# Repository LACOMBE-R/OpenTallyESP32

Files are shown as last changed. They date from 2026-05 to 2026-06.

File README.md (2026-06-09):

# OpenTallyESP32

A wireless tally light system built around the **Seeed XIAO ESP32-C3**. Each unit connects to a WebSocket tally server over Wi-Fi and lights up its two NeoPixel LEDs to show the live camera state (Program / Preview / Idle). Battery level is reported to the server automatically.

This project was created for the [orKs](https://lce.gg/) association for the **LCE** ([lce.gg](https://lce.gg/)) event, to manage camera tally signaling during live productions.

---

## Hardware

| Component | Details |
|---|---|
| MCU | Seeed Studio XIAO ESP32-C3 |
| LEDs | 3× NeoPixel (WS2812B), pin **D8** — 2 rear + 1 front-facing |
| Button | Tactile switch, pin **D1** (GPIO 3) |
| Battery sensing | Enable pin **D0**, ADC pin **D2** — voltage divider, 3.0 V–4.2 V range |

The KiCad schematic and PCB layout are in [`ECAD/OpenTallyESP32/`](ECAD/OpenTallyESP32/).

---

## Firmware

### Prerequisites

- [PlatformIO](https://platformio.org/) (VS Code extension or CLI)

### Credentials

Sensitive values (WiFi credentials, WebSocket server) are kept out of version control in a local file:

```
Firmware/OpenTallyESP32/include/credentials.h
```

This file is listed in `.gitignore` and will never be committed. Before building, copy the example file and fill in your values:

```bash
cp include/credentials.h.example include/credentials.h
```

```cpp
#define DEFAULT_WIFI_SSID  "your_ssid"
#define DEFAULT_WIFI_PASS  "your_password"
#define DEFAULT_WS_HOST    "your.websocket.server"
#define DEFAULT_WS_PORT    80
```

These defines are used as fallback defaults when no configuration has been saved to flash yet. Once configured via the dashboard, the flash values take over and these defaults are no longer used.

### Dependencies (resolved automatically by PlatformIO)

- `adafruit/Adafruit NeoPixel`
- `links2004/WebSockets`
- `bblanchon/ArduinoJson`

---

## Configuration

### NVS flash storage

Configuration is persisted in the ESP32's **NVS (Non-Volatile Storage)** — a key-value store built into the flash that survives resets and power cuts. The Arduino `Preferences` library is used to read and write it under the namespace `opentally`.

Values are written only when the user submits the config form; they are read once at every boot before anything else runs. If a key has never been written, the firmware falls back to the compiled-in default shown below.

| Key | Type | Default | Description |
|-----|---|---|---|
| `camera_id` | string | `cam01` | Camera identifier sent in every WebSocket message |
| `ws_host` | string | `your.websocket.server` | WebSocket server hostname |
| `ws_port` | uint16 | `80` | WebSocket server port |
| `wifi_ssid` | string | — | Wi-Fi network name |
| `wifi_pass` | string | — | Wi-Fi password |

### Entering configuration mode

Hold the button for **5 seconds** at power-on (or after waking from deep sleep). The LEDs will turn **solid purple** to confirm the long-press was detected.

The device starts a Wi-Fi access point:

- **SSID:** `OpenTally-Config`
- **Password:** `opentally`

Connect to it and open **http://192.168.4.1** in a browser. Fill in the form and click *Configurer*. The device saves the settings to NVS, confirms with a countdown banner, then restarts into normal mode.

### Operating modes — flowchart

```
                        ┌─────────────────┐
                        │   Power on /    │
                        │  Wake from deep │
                        │      sleep      │
                        └────────┬────────┘
                                 │
                        Load NVS config
                                 │
                    ┌────────────▼────────────┐
                    │  Button held on boot?   │
                    └────┬──────────────┬─────┘
                  Yes ≥5s│              │No
                         │              │
           ┌─────────────▼──┐    ┌──────▼───────────────┐
           │   AP / Config  │    │     Normal mode      │
           │     mode       │    │  Connect to Wi-Fi    │
           │ SSID: OpenTally│    └─────┬────────────────┘
           │ IP: 192.168.4.1│          │
           │ LEDs: purple   │    ┌─────▼─────────────────────┐
           │   blink        │    │  Wi-Fi connected in 30s?  │
           └─────────┬──────┘    └──┬─────────────────────┬──┘
                     │           No │                     │ Yes
              Serve config    ┌─────▼──────┐    ┌─────────▼──────────┐
                  form        │ Deep sleep │    │  Connect WebSocket │
                     │        └────────────┘    └─────────┬──────────┘
              User submits                                │
                     │                       ┌────────────▼───────────┐
              Save to NVS                    │      Main loop         │
                     │                       │  ┌──────────────────┐  │
                  Restart                    │  │ WS msg received  │  │
                                             │  │  → update LEDs   │  │
                                             │  │    RED / GREEN / │  │
                                             │  │      OFF         │  │
                                             │  └──────────────────┘  │
                                             │  ┌──────────────────┐  │
                                             │  │ Every 30s        │  │
                                             │  │ → send battery % │  │
                                             │  └──────────────────┘  │
                                             │  ┌──────────────────┐  │
                                             │  │ Button press     │  │
                                             │  │  → deep sleep    │  │
                                             │  └──────────────────┘  │
                                             └────────────────────────┘
```

---

## Operation

### Boot sequence

1. Device loads saved configuration from NVS.
2. If button is held ≥ 5 s → **AP / config mode** (see above).
3. Otherwise → **normal mode**: connects to the configured Wi-Fi.

### LED states

The device has two **rear LEDs** (visible to the operator) and one **front LED** (visible to the talent, facing the subject).

**Tally states**

| State | Rear LEDs (0 & 1) | Front LED (2) |
|---|---|---|
| Program (on air) | Red | Red |
| Preview | Green | Off |
| Program + Preview | Red (program takes priority) | Red |
| Idle | Off | Off |

**Status patterns**

Slow-blink patterns affect rear LEDs only (front LED stays off). Quick-flash patterns fill all 3 LEDs.

| Color | Pattern | Front LED | Meaning |
|---|---|---|---|
| Blue | Slow blink | Off | Connecting to Wi-Fi |
| Green | 5 quick flashes | On | Wi-Fi connected |
| Red | Slow blink | Off | WebSocket disconnected |
| Purple | Slow blink | Off | AP config mode active |
| Red | 3 quick flashes | On | Entering deep sleep |

### Power saving

- After Wi-Fi connects the CPU is throttled to **80 MHz** and Wi-Fi modem-sleep is enabled.
- Press the button at any time — including during Wi-Fi connection — to immediately enter **deep sleep**. The device will wake again on the next button press.
- If Wi-Fi does not connect within **30 seconds**, the device goes to deep sleep automatically.

### Battery reporting

On WebSocket connection, and every **30 seconds** thereafter, the device reads the battery voltage and sends the percentage to the tally server (only if the value changed). The server can display it in any connected control surface.

---

## WebSocket protocol

> **Note:** The WebSocket backend used at LCE is not open source. It pulls live camera states directly from a **Blackmagic ATEM** video switcher and broadcasts them to all connected tally units. However, the protocol is straightforward enough to reimplement — any server that speaks the JSON messages below can drive these tally units.

All messages are JSON objects with at least an `action` field and, where relevant, a `camera` field and a `content` object.

### Messages sent by the tally unit (firmware)

| Action | Extra fields | Description |
|---|---|---|
| `SubscribeCamera` | `camera` | Subscribe to state updates for the given camera ID. The server will push updates whenever the camera's program/preview state changes. |
| `GetCameraProperties` | `camera` | Request the current program/preview state of a camera immediately after connecting. |
| `SetBatteryLevel` | `camera`, `content.batteryLevel` (integer 0–100) | Report the tally unit's battery percentage to the server. Sent on connection, then every 30 s if the value changed. |

### Messages sent by the browser controller (`tally-control.html`)

| Action | Extra fields | Description |
|---|---|---|
| `ActAsSender` | — | Identifies this client as a control surface (sender), not a passive tally receiver. |
| `SubscribeCamera` | `camera` | Subscribe to state updates for a camera (same as firmware). |
| `GetCameraProperties` | `camera` | Request the current state immediately. |
| `SetCameraProperties` | `camera`, `content.program` (bool), `content.preview` (bool) | Set the tally state of a camera. Both fields must be present; at most one should be `true`. |

### Messages received from the server

| Trigger | Expected fields | Description |
|---|---|---|
| State change or reply to `GetCameraProperties` | `content.program` (bool), `content.preview` (bool) | Pushed to all subscribers whenever a camera's state changes. The firmware and browser controller both read these two booleans to update their display. |

---

## Browser control tool

[`tally-control.html`](tally-control.html) is a standalone HTML file intended primarily for **testing purposes** — useful to verify the WebSocket server is working and to trigger tally states without needing physical hardware. Open it in any browser, enter the WebSocket URL (e.g. `ws://your.websocket.server:80/`) and the camera ID, then click **Connecter**. You can then manually set a camera to **Idle**, **Preview**, or **Program**. All messages sent and received are shown in the log panel.

---

## Repository structure

```
OpenTallyESP32/
├── ECAD/
│   ├── LIB/                  KiCad symbol and footprint library (XIAO ESP32-C3)
│   └── OpenTallyESP32/       KiCad project (schematic, PCB layout)
│       ├── *.kicad_*         KiCad project files
│       ├── *.gbr / *.gbrjob  Gerber files for PCB manufacturing
│       ├── *.dxf             DXF exports
│       └── OpenTallyESP32PCB.step  3D STEP model
├── Firmware/
│   └── OpenTallyESP32/
│       ├── src/main.cpp      Full firmware source
│       ├── include/          credentials.h.example (copy to credentials.h before building)
│       ├── test/             Manual test sketches
│       └── platformio.ini    PlatformIO project config
└── tally-control.html        Browser-based tally controller
```

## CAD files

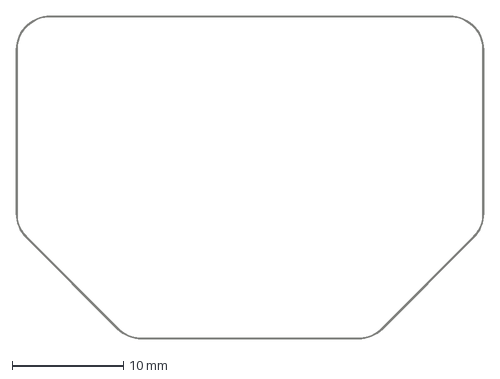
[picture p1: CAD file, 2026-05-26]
ECAD/OpenTallyESP32/OpenTallyESP32-Edge_Cuts.dxf
42.0 x 29.0 mm

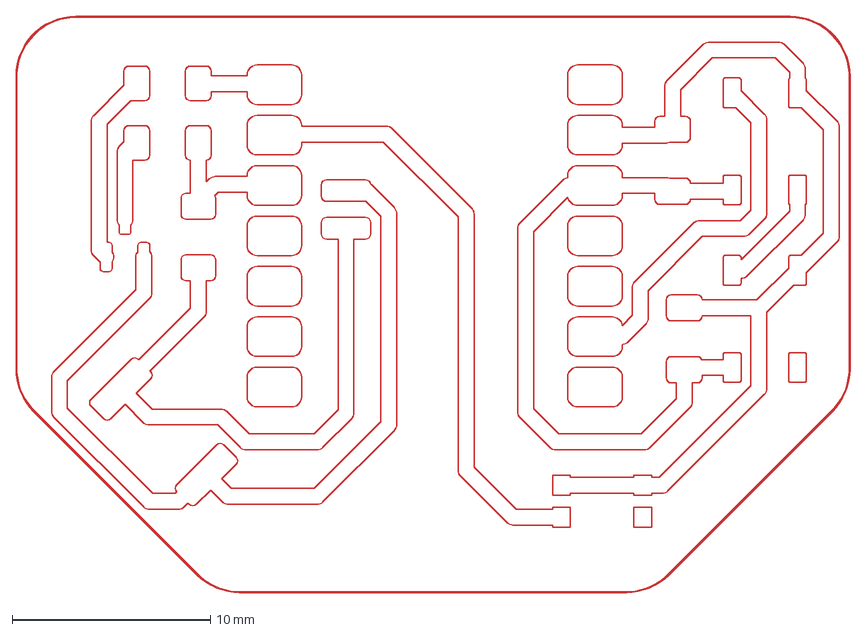
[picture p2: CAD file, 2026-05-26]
ECAD/OpenTallyESP32/OpenTallyESP32-F_Cu.dxf
42.0 x 29.0 mm

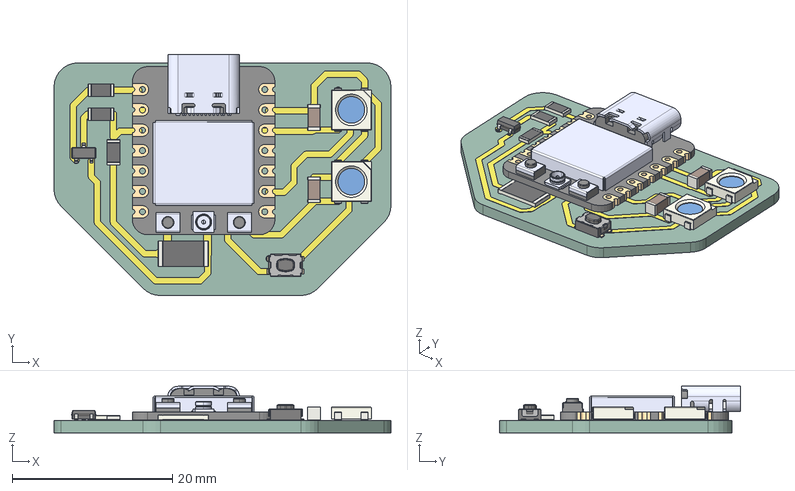
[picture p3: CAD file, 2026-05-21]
ECAD/OpenTallyESP32/OpenTallyESP32PCB.step
42.0 x 30.0 x 5.80 mm
C_1206_3216Metric x 2
LED_WS2812B_PLCC4_50x50mm_P32mm x 2
R_1206_3216Metric x 3
SOT-23
R_2512_6332Metric
SW_Push_1P1T_NO_CK_KMR2
OpenTallyESP32_copper
OpenTallyESP32_PCB

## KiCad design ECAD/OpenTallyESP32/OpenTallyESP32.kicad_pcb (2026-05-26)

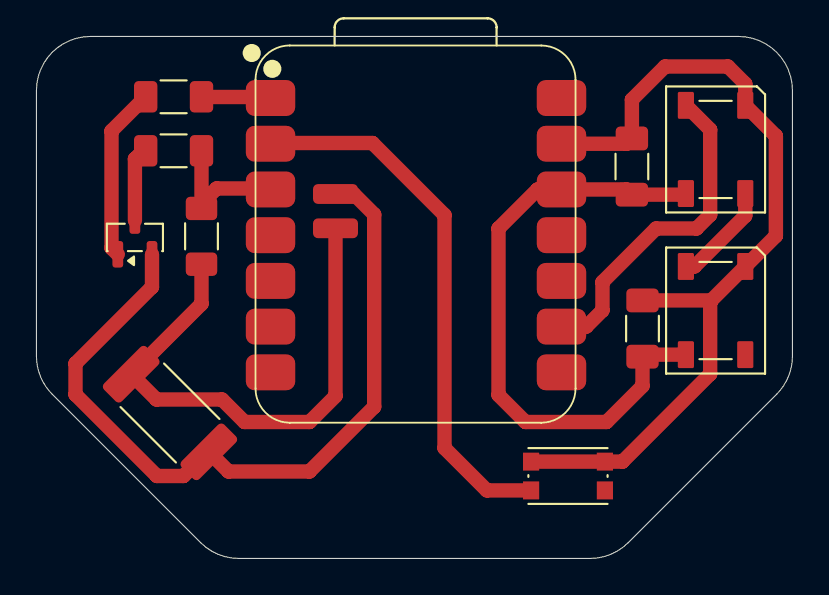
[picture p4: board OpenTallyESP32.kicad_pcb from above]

Board: 2 copper layers, 42.0 x 29.0 mm, 11 parts (0 on the bottom side), 11 nets.

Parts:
C1, C2: C_Small; C_1206_3216Metric_Pad1.33x1.80mm_HandSolder
D1, D2: WS2812B; LED_WS2812B_PLCC4_5.0x5.0mm_P3.2mm
J1: Conn_01x02; R_2512_6332Metric_Pad1.40x3.35mm_HandSolder
Q1: AO3400A; SOT-23
R1, R2, R3: R_Small; R_1206_3216Metric_Pad1.30x1.75mm_HandSolder
SW1: SW_Push; SW_Push_1P1T_NO_CK_KMR2
U1: XIAO ESP32C3; XIAO-ESP32-C3-SMD

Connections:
+3.3V: C1.1, C2.1, D1.1 (VDD), D2.1 (VDD), U1.12 (VCC_3V3)
+BATT: J1.2, R1.1, U1.15 (Batt+)
-BATT: J1.1, Q1.2 (S), U1.16 (Batt-)
BATT_LEVEL: R1.2, R2.1, U1.3 (D2)
BATT_READ: R3.1, U1.1 (D0)
GND: C1.2, C2.2, D1.3 (VSS), D2.3 (VSS), SW1.2, U1.13 (GND)
NEOPIXEL: D2.4 (DIN), U1.9 (D8)
unnamed: D1.4 (DIN), D2.2 (DOUT)
unnamed: Q1.3 (D), R2.2
unnamed: Q1.1 (G), R3.2
SW: SW1.1, U1.2 (D1)

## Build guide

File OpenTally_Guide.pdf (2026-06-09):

# OpenTally ESP32

Guide d'utilisation

## 1 Mode Config

Le mode Config permet de saisir les paramètres Wi-Fi, l'hôte WebSocket et l'identifiant caméra via une interface web embarquée. À activer avant la première utilisation ou pour modifier les paramètres réseau.

# | Action

1 | Maintenir le bouton enfoncé 5 secondes : l'appareil se met sous tension et active le mode Config.
■ Violet — clignotement lent | Les LEDs passent en violet clignotant : un access point « OpenTally-Config » est créé.
2 | Se connecter au réseau Wi-Fi « OpenTally-Config » (MDP : opentally).
3 | Ouvrir http://192.168.4.1 dans un navigateur.
4 | Remplir le formulaire et cliquer sur Configurer.
5 | L'appareil sauvegarde les paramètres et redémarre en mode normal.

## 2 Mode normal

# | Action du device | Signal LED

1 | Appui court sur le bouton (ou sortie du mode Config) : l'appareil se met sous tension | Aucun
2 | Connexion au réseau Wi-Fi configuré | ■ Bleu — clignotement lent
3 | Wi-Fi connecté | ■ Vert — 5 flashs rapides
4 | Connexion au serveur WebSocket | ■ Rouge — clignotement lent si échec
5 | WebSocket connecté — en attente de tally | LEDs éteintes

États tally (une fois connecté au WebSocket)

État caméra | LEDs arrière (opérateur) | LED avant (talent)
Program | ■ Rouge fixe | ■ Rouge fixe
Preview | ■ Vert fixe | ■ Éteinte
Program + Preview | ■ Rouge fixe (priorité Program) | ■ Rouge fixe
Idle (inactif) | ■ Éteinte | ■ Éteinte

## 3 Gestion de l'alimentation

Action | Effet
Appui bouton | Mise hors tension immédiate (en mode normal ou pendant la connexion Wi-Fi). Appuyer à nouveau pour rallumer.
Pas de Wi-Fi après 30 s | Mise hors tension automatique.

Niveau de batterie : envoyé automatiquement au serveur à la connexion WebSocket, puis toutes les 30 secondes si la valeur a changé.

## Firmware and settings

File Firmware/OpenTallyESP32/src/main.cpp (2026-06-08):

#include <Arduino.h>
#include "credentials.h"
#include <WiFi.h>
#include <WebServer.h>
#include <WebSocketsClient.h>
#include <ArduinoJson.h>
#include <Adafruit_NeoPixel.h>
#include <Preferences.h>
#include "esp_sleep.h"

// ── Pins ──────────────────────────────────────────────────────────────────────
#define PIN_NEOPIXEL   D8
#define PIN_BUTTON     D1
#define PIN_BATT_READ  D0
#define PIN_BATT_ADC   D2
#define NUM_PIXELS     3
#define GPIO_BUTTON    3      // D1 = GPIO3 sur XIAO ESP32C3

// ── Config ────────────────────────────────────────────────────────────────────
#define VBATT_FULL_MV   4200
#define VBATT_EMPTY_MV  3000
#define LONG_PRESS_MS   5000
#define WIFI_TIMEOUT_MS 30000

// ── Globals ───────────────────────────────────────────────────────────────────
Adafruit_NeoPixel pixels(NUM_PIXELS, PIN_NEOPIXEL, NEO_GRB + NEO_KHZ800);
WebSocketsClient  wsClient;
WebServer         server(80);
Preferences       prefs;

String   cfg_camera_id;
String   cfg_ws_host;
uint16_t cfg_ws_port;
String   cfg_wifi_ssid;
String   cfg_wifi_pass;

// ── Persistance ───────────────────────────────────────────────────────────────
void loadConfig() {
  prefs.begin("opentally", true);
  cfg_camera_id = prefs.getString("camera_id", "cam01");
  cfg_ws_host   = prefs.getString("ws_host",   DEFAULT_WS_HOST);
  cfg_ws_port   = prefs.getUShort("ws_port",   DEFAULT_WS_PORT);
  cfg_wifi_ssid = prefs.getString("wifi_ssid", DEFAULT_WIFI_SSID);
  cfg_wifi_pass = prefs.getString("wifi_pass", DEFAULT_WIFI_PASS);
  prefs.end();
}

void saveConfig(const String& camera_id, const String& ws_host, uint16_t ws_port,
                const String& wifi_ssid, const String& wifi_pass) {
  prefs.begin("opentally", false);
  prefs.putString("camera_id", camera_id);
  prefs.putString("ws_host",   ws_host);
  prefs.putUShort("ws_port",   ws_port);
  prefs.putString("wifi_ssid", wifi_ssid);
  prefs.putString("wifi_pass", wifi_pass);
  prefs.end();
}

// ── LED helpers ───────────────────────────────────────────────────────────────

// Status LEDs (pixels 0 & 1) — used for Wi-Fi / sleep / AP blink patterns
void setStatusLeds(uint8_t r, uint8_t g, uint8_t b) {
  pixels.setPixelColor(0, pixels.Color(r, g, b));
  pixels.setPixelColor(1, pixels.Color(r, g, b));
  pixels.setPixelColor(2, pixels.Color(0, 0, 0));
  pixels.show();
}

// Convenience alias for single-color fills (e.g. deep-sleep flash)
void setLeds(uint8_t r, uint8_t g, uint8_t b) {
  pixels.fill(pixels.Color(r, g, b));
  pixels.show();
}

void ledsOff() {
  pixels.clear();
  pixels.show();
}

// Tally state: pixels 0 & 1 = rear, pixel 2 = front (program only)
// program takes priority over preview when both are true
void setTally(bool program, bool preview) {
  if (program) {
    pixels.setPixelColor(0, pixels.Color(200, 0, 0));  // rear: red
    pixels.setPixelColor(1, pixels.Color(200, 0, 0));
    pixels.setPixelColor(2, pixels.Color(200, 0, 0));  // front: red
  } else if (preview) {
    pixels.setPixelColor(0, pixels.Color(0, 200, 0));  // rear: green
    pixels.setPixelColor(1, pixels.Color(0, 200, 0));
    pixels.setPixelColor(2, pixels.Color(0, 0, 0));    // front: off
  } else {
    pixels.clear();
  }
  pixels.show();
}

// ── Batterie ──────────────────────────────────────────────────────────────────
int readBatteryPercent() {
  digitalWrite(PIN_BATT_READ, HIGH);
  delay(10);
  int raw = analogRead(PIN_BATT_ADC);
  digitalWrite(PIN_BATT_READ, LOW);
  int mv = (int)((long)raw * 3300 * 2 / 4095);
  return constrain(map(mv, VBATT_EMPTY_MV, VBATT_FULL_MV, 0, 100), 0, 100);
}

// ── Deep sleep ────────────────────────────────────────────────────────────────
void goDeepSleep() {
  for (int i = 0; i < 3; i++) {
    setLeds(200, 0, 0);
    delay(80);
    ledsOff();
    delay(80);
  }
  delay(100);
  esp_deep_sleep_enable_gpio_wakeup(1ULL << GPIO_BUTTON, ESP_GPIO_WAKEUP_GPIO_LOW);
  esp_deep_sleep_start();
}

// ── WebSocket ─────────────────────────────────────────────────────────────────
bool wsConnected = false;

void onWsEvent(WStype_t type, uint8_t* payload, size_t length) {
  if (type == WStype_CONNECTED) {
    wsConnected = true;
    Serial.println("WS connecté");
    String sub = "{\"action\":\"SubscribeCamera\",\"camera\":\"" + cfg_camera_id + "\"}";
    String get = "{\"action\":\"GetCameraProperties\",\"camera\":\"" + cfg_camera_id + "\"}";
    wsClient.sendTXT(sub);
    wsClient.sendTXT(get);
    int batt = readBatteryPercent();
    String battMsg = "{\"action\":\"SetBatteryLevel\",\"camera\":\"" + cfg_camera_id
                   + "\",\"content\":{\"batteryLevel\":" + String(batt) + "}}";
    wsClient.sendTXT(battMsg);

  } else if (type == WStype_TEXT) {
    JsonDocument doc;
    if (deserializeJson(doc, payload)) return;

    bool program = doc["content"]["program"] | false;
    bool preview = doc["content"]["preview"] | false;
    setTally(program, preview);

  } else if (type == WStype_DISCONNECTED) {
    wsConnected = false;
    Serial.println("WS déconnecté");
  }
}

// ── Mode AP + dashboard ───────────────────────────────────────────────────────
void handleConfigPage() {
  int batt = readBatteryPercent();
  bool saved = server.hasArg("saved");

  String banner = saved
    ? "<div class='ok'>Configuration sauvegardée — redémarrage dans <span id='c'>4</span>s..."
      "<script>let n=4;setInterval(()=>{n--;document.getElementById('c').textContent=n},1000)</script>"
      "</div>"
    : "";

  String html =
    "<!DOCTYPE html><html><head>"
    "<meta charset='utf-8'><meta name='viewport' content='width=device-width,initial-scale=1'>"
    "<title>OpenTally</title><style>"
    "*{box-sizing:border-box}"
    "body{font-family:sans-serif;background:#1a1a2e;color:#eee;"
      "display:flex;justify-content:center;padding:30px 16px;margin:0}"
    ".card{background:#16213e;border-radius:16px;padding:32px;width:100%;max-width:440px}"
    "h1{margin:0 0 4px;font-size:1.4rem}"
    ".batt{color:#aaa;font-size:.9rem;margin-bottom:28px}"
    ".ok{background:#1b4332;border:1px solid #2d6a4f;border-radius:8px;padding:12px 14px;"
      "font-size:.9rem;color:#74c69d;margin-bottom:20px}"
    "label{display:block;font-size:.8rem;color:#aaa;margin:14px 0 4px;text-transform:uppercase;letter-spacing:.05em}"
    "input{width:100%;padding:10px 12px;border-radius:8px;border:1px solid #2a2a4a;"
      "background:#0f3460;color:#fff;font-size:1rem}"
    ".sep{border:none;border-top:1px solid #2a2a4a;margin:20px 0}"
    "button{margin-top:24px;width:100%;padding:13px;border-radius:8px;border:none;"
      "background:#e94560;color:#fff;font-size:1rem;font-weight:700;cursor:pointer}"
    "</style></head><body><div class='card'>"
    "<h1>OpenTally</h1>"
    "<div class='batt'>Batterie : " + String(batt) + " %</div>"
    + banner +
    "<form method='POST' action='/save'>"
    "<label>ID Caméra</label>"
    "<input name='camera_id' value='" + cfg_camera_id + "'>"
    "<hr class='sep'>"
    "<label>Host WebSocket</label>"
    "<input name='ws_host' value='" + cfg_ws_host + "'>"
    "<label>Port WebSocket</label>"
    "<input name='ws_port' type='number' value='" + String(cfg_ws_port) + "'>"
    "<hr class='sep'>"
    "<label>SSID WiFi</label>"
    "<input name='wifi_ssid' value='" + cfg_wifi_ssid + "'>"
    "<label>Mot de passe WiFi</label>"
    "<input name='wifi_pass' type='password' value='" + cfg_wifi_pass + "'>"
    "<button type='submit'>Configurer</button>"
    "</form></div></body></html>";

  server.send(200, "text/html", html);
}

void handleSave() {
  saveConfig(
    server.arg("camera_id"),
    server.arg("ws_host"),
    (uint16_t)server.arg("ws_port").toInt(),
    server.arg("wifi_ssid"),
    server.arg("wifi_pass")
  );
  loadConfig();  // met à jour les variables globales

  // PRG : redirect GET pour éviter le re-POST au refresh
  server.sendHeader("Location", "/?saved=1");
  server.send(303);

  // Laisse le temps au navigateur de charger la page de confirmation
  delay(4000);
  ESP.restart();
}

void runAPMode() {
  WiFi.softAP("OpenTally-Config", "opentally");
  Serial.print("AP démarré — IP: ");
  Serial.println(WiFi.softAPIP());

  server.on("/",      HTTP_GET,  handleConfigPage);
  server.on("/save",  HTTP_POST, handleSave);
  server.begin();

  bool ledState = false;
  unsigned long lastBlink = 0;

  while (true) {
    server.handleClient();
    if (millis() - lastBlink > 800) {
      lastBlink = millis();
      ledState = !ledState;
      if (ledState) setStatusLeds(80, 0, 80); else ledsOff();
    }
  }
}

// ── Mode normal : WiFi + WebSocket ────────────────────────────────────────────
void runNormalMode() {
  WiFi.begin(cfg_wifi_ssid.c_str(), cfg_wifi_pass.c_str());
  Serial.print("Connexion WiFi...");

  bool ledState = false;
  unsigned long lastBlink   = 0;
  unsigned long connectStart = millis();

  // Clignotement bleu pendant la connexion
  while (WiFi.status() != WL_CONNECTED) {
    if (millis() - connectStart > WIFI_TIMEOUT_MS) {
      Serial.println("\nTimeout WiFi → deep sleep");
      goDeepSleep();
    }
    if (digitalRead(PIN_BUTTON) == LOW) {
      delay(50);
      if (digitalRead(PIN_BUTTON) == LOW) {
        while (digitalRead(PIN_BUTTON) == LOW) delay(10);
        goDeepSleep();
      }
    }
    if (millis() - lastBlink > 400) {
      lastBlink = millis();
      ledState = !ledState;
      if (ledState) setStatusLeds(0, 0, 200); else ledsOff();
    }
  }
  Serial.println("\nWiFi OK: " + WiFi.localIP().toString());
  setCpuFrequencyMhz(80);
  WiFi.setSleep(true);

  // 5 flashs verts à la connexion
  for (int i = 0; i < 5; i++) {
    setLeds(0, 200, 0);
    delay(80);
    ledsOff();
    delay(80);
  }

  // Connexion WebSocket
  wsClient.begin(cfg_ws_host, cfg_ws_port, "/");
  wsClient.onEvent(onWsEvent);
  wsClient.setReconnectInterval(3000);

  // Boucle principale tally
  lastBlink = 0;
  ledState  = false;
  unsigned long lastBattCheck = 0;
  int lastBattPercent = -1;
  unsigned long wsGraceEnd = millis() + 4000;  // 4s de noir avant d'afficher l'erreur WS

  while (true) {
    wsClient.loop();

    // Vérification batterie toutes les 30s, envoi uniquement si le % a changé
    if (wsConnected && millis() - lastBattCheck > 30000) {
      lastBattCheck = millis();
      int batt = readBatteryPercent();
      if (batt != lastBattPercent) {
        lastBattPercent = batt;
        String msg = "{\"action\":\"SetBatteryLevel\",\"camera\":\"" + cfg_camera_id
                   + "\",\"content\":{\"batteryLevel\":" + String(batt) + "}}";
        wsClient.sendTXT(msg);
        Serial.println("Batterie envoyée : " + String(batt) + "%");
      }
    }

    // Blink rouge lent si WS déconnecté (après la période de grâce)
    if (!wsConnected && millis() > wsGraceEnd) {
      if (millis() - lastBlink > 900) {
        lastBlink = millis();
        ledState = !ledState;
        if (ledState) setStatusLeds(180, 0, 0); else ledsOff();
      }
    }

    // Appui bouton → deep sleep
    if (digitalRead(PIN_BUTTON) == LOW) {
      delay(50);
      if (digitalRead(PIN_BUTTON) == LOW) {
        while (digitalRead(PIN_BUTTON) == LOW) delay(10);
        goDeepSleep();
      }
    }
  }
}

// ── Setup ─────────────────────────────────────────────────────────────────────
void setup() {
  Serial.begin(115200);

  pinMode(PIN_BATT_READ, OUTPUT);
  digitalWrite(PIN_BATT_READ, LOW);
  pinMode(PIN_BUTTON, INPUT_PULLUP);

  pixels.begin();
  pixels.setBrightness(80);
  ledsOff();

  loadConfig();

  // Mesure durée d'appui pour déterminer le mode
  unsigned long pressStart = millis();
  bool longPress = false;

  while (digitalRead(PIN_BUTTON) == LOW) {
    if (millis() - pressStart >= LONG_PRESS_MS) {
      longPress = true;
      setStatusLeds(80, 0, 80);   // Violet = long press confirmé
      break;
    }
    delay(10);
  }

  // Attendre relâchement
  while (digitalRead(PIN_BUTTON) == LOW) delay(10);

  if (longPress) {
    runAPMode();
  } else {
    runNormalMode();
  }
}

void loop() {}

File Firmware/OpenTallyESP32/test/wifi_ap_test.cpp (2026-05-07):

// Test: Access Point simple
// Flasher ce fichier manuellement en le copiant dans src/main.cpp

#include <Arduino.h>
#include <WiFi.h>

const char* AP_SSID = "OpenTally-Test";
const char* AP_PASSWORD = "12345678";

void setup() {
  Serial.begin(115200);

  WiFi.softAP(AP_SSID, AP_PASSWORD);

  Serial.println("Access Point démarré");
  Serial.print("SSID: ");
  Serial.println(AP_SSID);
  Serial.print("IP: ");
  Serial.println(WiFi.softAPIP());
}

void loop() {
  Serial.print("Clients connectés: ");
  Serial.println(WiFi.softAPgetStationNum());
  delay(5000);
}

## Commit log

2026-03-15 Kicad project creation
    [OpenTallyESP32.kicad_pcb, OpenTallyESP32.kicad_sch]
2026-05-05 Added ESP32
    [OpenTallyESP32.kicad_sch]
2026-05-06 Jeff a terminé la chignole
    [OpenTallyESP32.kicad_pcb, OpenTallyESP32.kicad_sch]
2026-05-07 Added Firmware and HTML minimal controler
    [OpenTallyESP32-Edge_Cuts.dxf, OpenTallyESP32-F_Cu.dxf, OpenTallyESP32.kicad_pcb]
2026-05-07 Modified behavior and added battery level upstream
2026-05-07 PCB Save
    [OpenTallyESP32.kicad_sch]
2026-05-21 Added README.md
    [OpenTallyESP32.kicad_pcb, OpenTallyESP32.kicad_sch, OpenTallyESP32PCB.step]
2026-05-21 Fixed operating modes flowchart
2026-05-21 Fixed flowchart
2026-05-21 Fix flowchart arrow
2026-05-21 Moved battery solder pads and minor tweaks to routing
    [OpenTallyESP32.kicad_pcb, OpenTallyESP32PCB.step]
2026-05-26 Updated PCB for better integration and exported manufacturing files
    [OpenTallyESP32-Edge_Cuts.dxf, OpenTallyESP32-F_Cu.dxf, OpenTallyESP32.kicad_pcb]
2026-06-05 updated code to 3 WS2812 and created fab files for pcb
    [OpenTallyESP32-Edge_Cuts.gbr, OpenTallyESP32-F_Cu.gbr, OpenTallyESP32-F_Paste.gbr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]
2026-06-06 Update configuration and documentation for 3 NeoPixels; add status LED functionality
2026-06-09 Update README with LED status patterns and add OpenTally guide PDF
